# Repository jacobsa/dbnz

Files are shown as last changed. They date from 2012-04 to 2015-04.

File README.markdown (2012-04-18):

This is a hobbyist hardware project to design and physically build a computer
with a single instruction, `DBNZ`, which stands for _Decrement and Branch if
Non-Zero_. The computer has a dead-simple interface inspired by the
[Altair 8800][altair], and is built from discrete logic ICs (the only thing more
complicated being an SRAM chip).

[altair]: http://en.wikipedia.org/wiki/Altair_8800

Architecture
------------

The machine has 256 bytes of memory. Instructions are of the following form:

    DBNZ x, y

where `x` and `y` are each bytes. In machine code, this instruction is simply
the byte `x` followed by the byte `y`.

Given the instruction above, the computer decrements the value at memory
location `x`, then jumps to the instruction whose first byte is located at
memory location `y` if `x`'s post-decrement value is non-zero. Otherwise, if the
post-decrement value at `x` is zero, it moves on to the next instruction (whose
first byte is located after the second byte of the present instruction).

The computer has a register called `PC` which holds the location of the
instruction byte currently being processed (the first or the second byte of the
instruction), and a register called `VAL` that holds the value being
decremented, pre-decrement. If `PC` is ever equal to `0xFF`, the computer halts
immediately.

Human interface
---------------

Here's a crappy sketch:

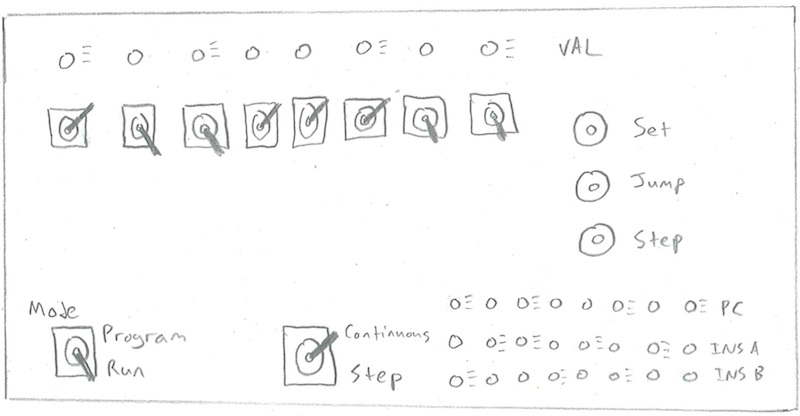
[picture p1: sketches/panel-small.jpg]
Front panel


The computer's main interface consists of a set of 8 LEDs and a set of 8
toggle switches, along with a `Set` button, a `Jump` button, and a `Step`
button. There is an additional toggle switch that allows you to switch between
program mode and run mode, and further LEDs to show internal state.

The user starts by turning on the computer (putting its memory into an undefined
state) and switching to program mode. This mode allows you to set up a program
in memory. You can move to a particular memory location by setting its address
on the toggle switches and pressing `Jump`. The new location's address appears
in the `PC` LEDs. You can set the memory location's value by configuring the
toggle switches appropriate, then pressing `Set`. This also moves you to the
next memory location.

When you are ready to run the program, jump to the appropriate entry point and
then switch to run mode. The computer will run the program until it halts,
showing the contents of the `VAL` register at the time it halted.

If you want to step through the program more slowly, setting the
`Continuous/Step` toggle to `Step` will allow you to do so using the `Step`
button. The computer will wait for this button after each instruction is
executed. In this mode, as in program mode, you can use the toggle switches and
the `Jump` button to jump around in memory.

Programming
-----------

I believe this machine is Turing-complete, though I haven't proved it. You can
start with simple subroutines and build up. For example, here is `CLEAR x` (set
the value at `x` to zero), assuming you return by falling off the end:

    // CLEAR x
    A: DBNZ x, A

Here is an unconditional jump:

    // GOTO L. 0xF0 is arbitrarily-chosen scratch space, and is destroyed.
    DBNZ 0xF0, L
    DBNZ 0xF0, L

And so on. You can use the following convention to halt with a particular value
on the LEDs.

 1. Choose a location to hold the return value, say `0xAA`.
 2. End your program with the following snippet located at `0xFD:

        // Cause the return value to be loaded, then jump to 0xFF. Because this
        // instruction is located two bytes before 0xFF, we will jump there no
        // matter what the value at 0xAA.
        DBNZ 0xAA 0xFF

 3. Compute the return value however you like, storing it at `0xAA`.
 4. Use `GOTO 0xFD` when done.

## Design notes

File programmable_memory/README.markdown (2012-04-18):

This is a starter project to build only part of the DBNZ machine described in
the main [readme][] file. It is a little gadget that allows you to set and read
back values from a 4-bit memory:

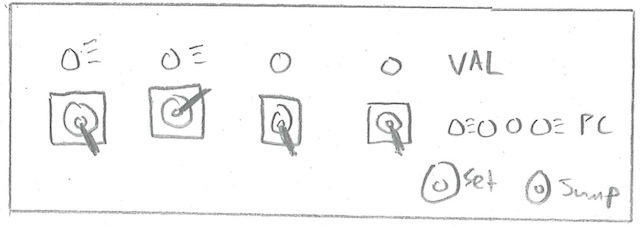
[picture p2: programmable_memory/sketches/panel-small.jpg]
Programmable memory front panel


All of the controls work the same as the corresponding ones in the larger
machine.

[readme]: https://github.com/jacobsa/dbnz#readme

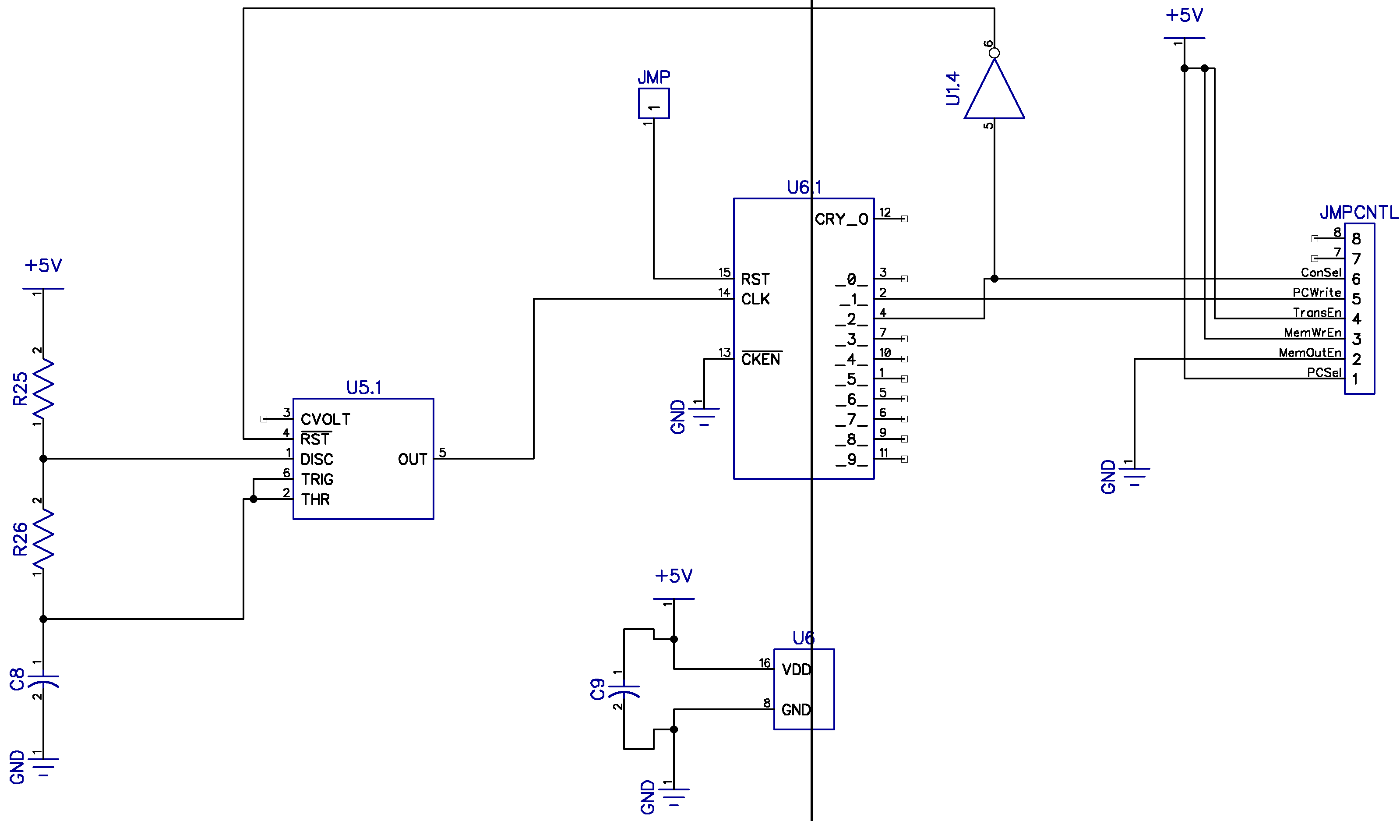
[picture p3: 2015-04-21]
programmable_memory/schematics/JMP control.png

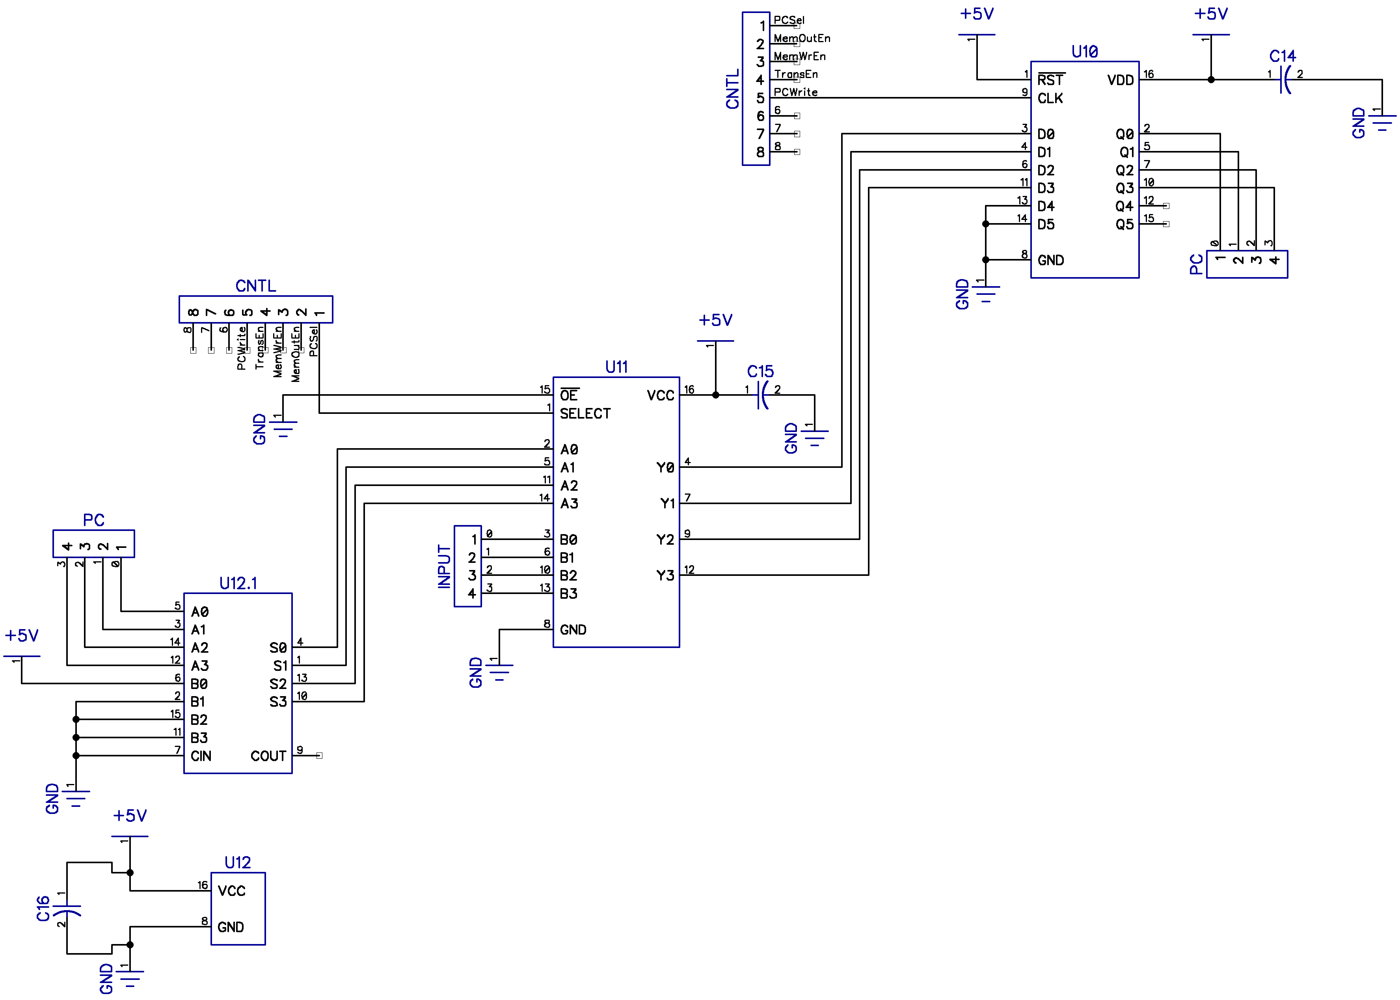
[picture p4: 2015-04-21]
programmable_memory/schematics/PC.png

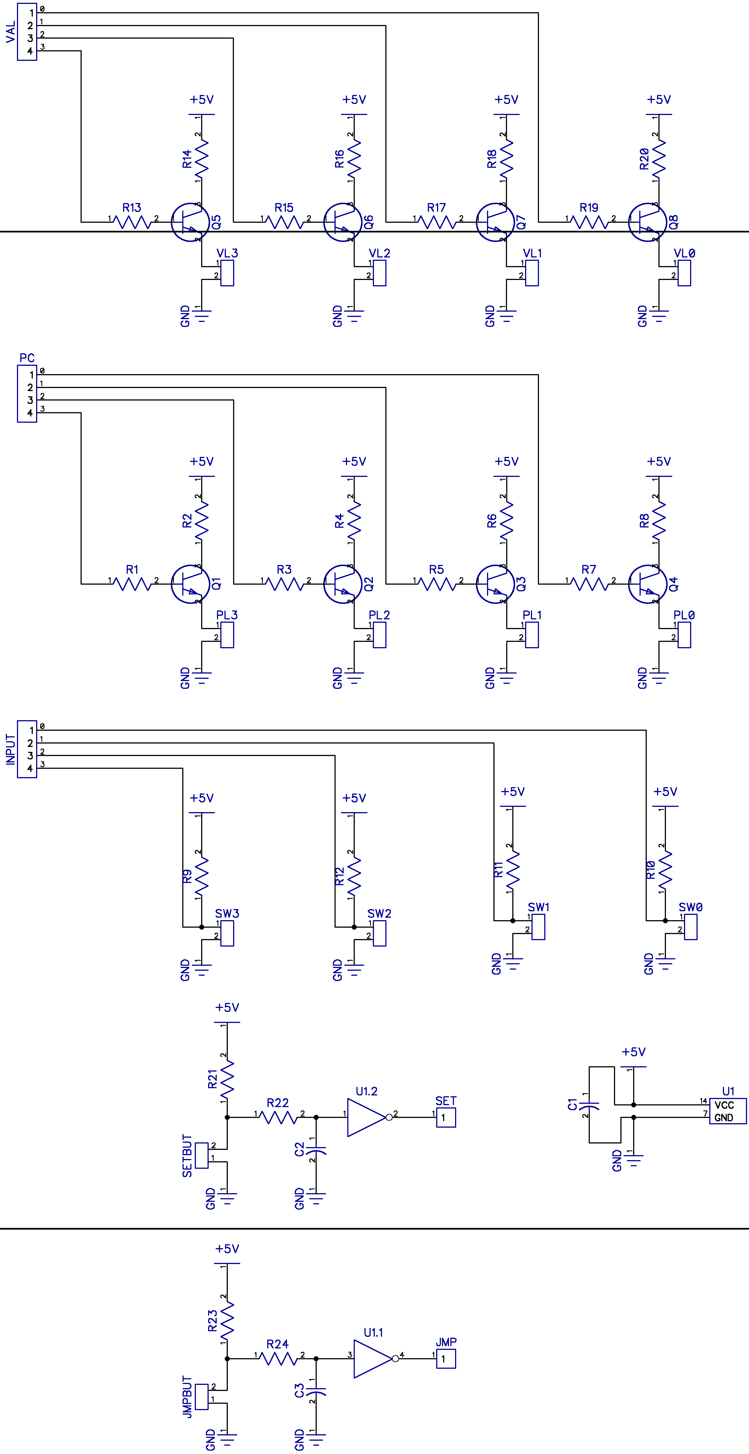
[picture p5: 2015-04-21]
programmable_memory/schematics/Control panel.png

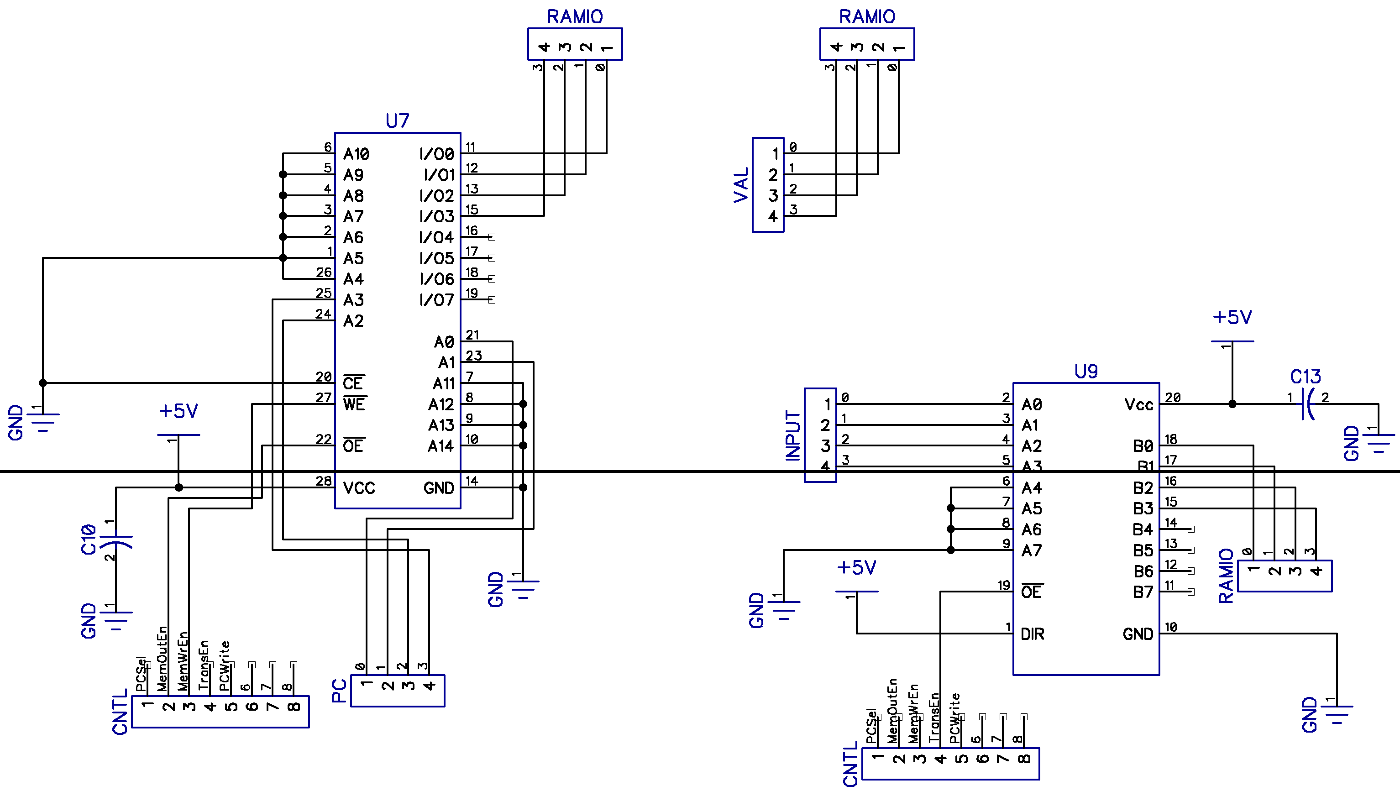
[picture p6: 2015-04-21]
programmable_memory/schematics/SRAM.png

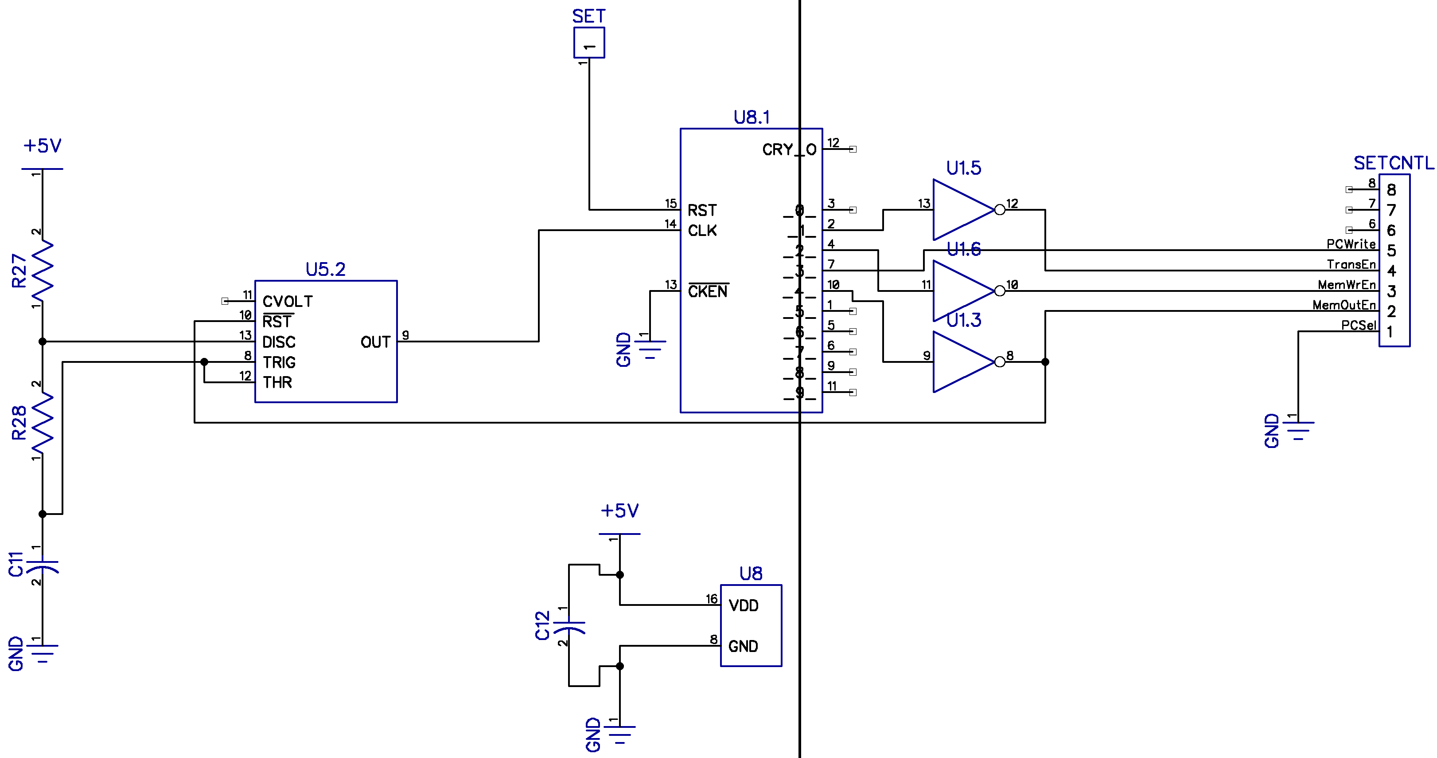
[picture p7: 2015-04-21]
programmable_memory/schematics/SET control.png

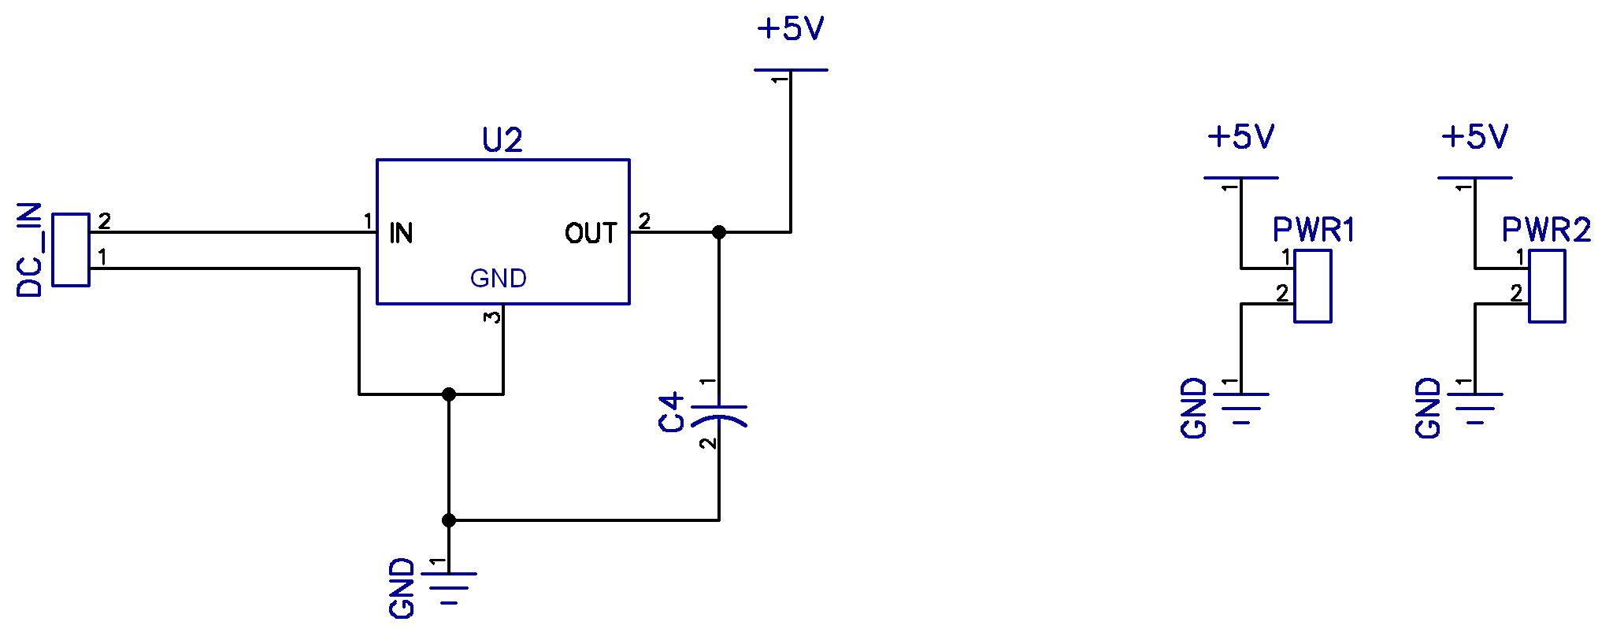
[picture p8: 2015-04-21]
programmable_memory/schematics/Power.png

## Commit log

2012-04-18 Started on value LEDs.
2012-04-18 Further LED work.
2012-04-18 Fixed LED numbering.
2012-04-19 Added a 2-pin connector part.
2012-04-19 Replaced LEDs with connectors.
2012-04-19 Added switche ports with pull-ups.
2012-04-19 Added LEDs for the PC register.
2012-04-19 Added 7414 for button debouncing.
2012-04-19 Added JMP and SET buttons.
2012-04-19 Added a power input port.
2012-04-19 Added two power output headers.
2012-04-25 Fixed VAL LED header numbering.
2012-04-25 Added a sheet for data circuits.
2012-04-25 Hooked up VAL LEDs.
2012-04-25 Hooked up a couple of PC pins.
2012-04-25 Started on PCB.
2012-04-25 Added a board outline.
2012-04-25 Added mounting holes.
2012-04-25 Placed headers for LEDs and switches.
2012-04-25 Placed button and power stuff.
2012-04-25 Switched IC sides and routed.
2012-04-25 Added a board shape to the top silk layer, for seeed studio.
2012-04-25 Switched to a roundrect outline.
2012-04-25 Exported manufacturing files.
    [Board.gbr, BoardOutline.gbr, Bottom.gbr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]
2012-04-25 Renamed to ITead's required naming format.
    [Board.gbr, BoardOutline.gbr, BottomAssy.gbr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]
2012-04-26 Added a missing capacitance value.
2012-04-26 Removed values from switches.
2015-04-21 Exported schematics at HEAD as PNG files.
2015-04-22 Added a DipTrace ASCII version of the schematic.
    This can be used to "easily" find more info than is in legend.txt,
    without opening DipTrace.
